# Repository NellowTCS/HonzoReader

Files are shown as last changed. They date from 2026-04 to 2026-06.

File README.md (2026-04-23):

# PocketMage PDA
[Please note that this project is in Beta]

@Ashtf 2025





# [Project Summary]
  This project is a PDA powered by an ESP32-S3 running a custom OS written in C++ using PlatformIO. This project utilizes an E-Ink and OLED screen in tandem to mitigate the refresh rate restrictions of an E-Ink panel while retaining the aesthetics and benefits of using E-Ink. This project is a work in progress and currently amounts to a simple GUI for navigating between apps, a text (.txt) file editor, and a basic file manager. More applications are planned for the future and a list of TO-DOs can be found below.

  At this point, the plan for this project is to get the software and hardware to maturity and once a finished product is achieved, a few things will happen. First, the project files (Code, KiCad schematics, 3D files) will be open-sourced and free for anyone to access. Next, I will likely begin selling kits that allow people to purchase all the parts required to build a device for themselves if they don't want to source the parts themselves. Finally, the community will be encouraged to help develop the software for the device and hopefully push it even further than I could myself.

  I will try my best to keep this GitHub up to date with the development of the device.

# [Getting Started]
**Helpful Resources:**

[FAQ](https://ashtf8.github.io/PocketMage_PDA/docs/faq)

[Tutorials](https://ashtf8.github.io/PocketMage_PDA/docs/tutorials)

[PocketMage Command & Keystroke Manual](https://ashtf8.github.io/PocketMage_PDA/docs/command-manual)

[3rd Party App Template](https://github.com/ashtf8/PocketMage_PDA/blob/main/Code/PocketMage_V3/src/APP_TEMPLATE.cpp)

  Check the [APP_TEMPLATE.cpp](./Code/PocketMage_V3/src/APP_TEMPLATE.cpp) and [/Code/PocketMage_V3/src/readme.md](./Code/PocketMage_V3/src/readme.md) file for more information. Check out the following video as a tutorial on how to create and format your app:
[Developing For the PocketMage](https://www.youtube.com/watch?v=3Ytc-3-BbMM)

# [Hardware]
- ESP32-S3 WROOM1 with 16mb flash and 8mb RAM. WiFi and Bluetooth supported.
- 3.1" 320x240px 1-bit SPI Eink panel (GDEQ031T10) with integrated driver
- 256x32px 1-bit SPI OLED (SSD1326, ER-OLED018-1W) with integrated driver
- MicroSD card slot with support for up to 2TB
- TCA8418 I2C Keyboard Matrix IC
- Piezo Buzzer (Simple Tones)
- Power Button
- 1200mAh pouch-style LiPo battery with JST PH (2mm) connector
- USB Type-C connector
- PCF8563T I2C RTC (Real Time Clock) module
- Expansion port with the following breakouts:
    - +3.3v
    - GND
    - I2C SDA
    - I2C SCL
    - SPI MOSI
    - SPI SCK
    - SPI MISO
    - GPIO A
    - GPIO B
    - GPIO C
    - GPIO D / UART TX (changeable with solder jumper, default TX)
    - GPIO E / UART RX (changeable with solder jumper, default RX)

# [Software]
- Text editor app
- FileWizard file-management app
- Calendar app
- USB file transfer app
- Settings app
- Tasks app
- Journal app
- Dictionary app (Lexicon)
- Basic commands supported through the home menu:
    - roll dN (dice roll, N=number of sides)
    - set time and date
    - directly open files in Notes or FileWiz by typing the name
    - etc.

# [Planned Features]
- Timers and alarms
- E-book reader
- WiFi notes/calendar sync (Google Docs/Calendar)
- LoRa/Meshtastic add-on module
- Battery expansion add-on module
- Custom abbreviations
- Bluetooth keyboard support

# License
All files are distributed under Apache-2.0 license:

PocketMage PDA - A clamshell note-taking and productivity device using E-Ink and OLED.



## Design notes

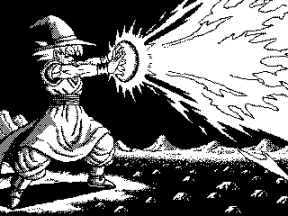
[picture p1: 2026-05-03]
Resources/Assets/screensavers/powerbeam_forest927.bmp

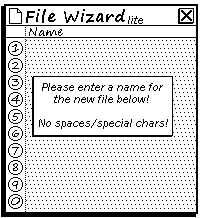
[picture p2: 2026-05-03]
Resources/Assets/File Wizard/fileWizLite3.bmp

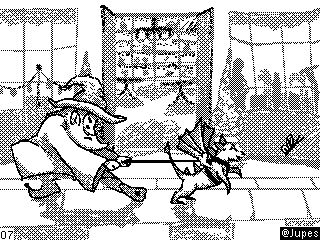
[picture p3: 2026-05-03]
Resources/Assets/ScreenSaver/New folder/classic (8).bmp

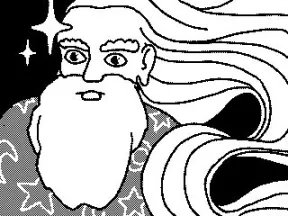
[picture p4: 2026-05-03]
Resources/Assets/screensavers/beautifulhair_b4by_dr1v3r.bmp

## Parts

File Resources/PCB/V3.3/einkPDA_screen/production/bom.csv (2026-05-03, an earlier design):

Designator | Footprint | Quantity | Value | LCSC Part #
C1, C10, C3, C4, C5, C6, C7, C8, C9 | 0402 | 9 | 1uF | C52923
C11 | 0805 | 1 | 4.7uF | C1779
C12, C2 | 0402 | 2 | 4.7uF | C23733
C13, C14 | 0402 | 2 | 0.1uF | C1525
D1, D2, D3 | D_SOD-123 | 3 | MBR0530 | C77336
J2 | AFE03-S25FMA-1H | 1 | ~ | C262544
J3 | TouchSlider-9_50x10mm | 1 | CapacitiveTouch
J4 | AFC01-S12FCA-00 | 1 | Conn_01x12_Pin | C262661
L1 | L_Cenker_CKCS5020 | 1 | 10uH | C52281
Q1 | SOT-323_SC-70 | 1 | Si1308EDL | C7603347
R1 | 0603 | 1 | 0.47R | C3013349
R2 | 0805 | 1 | 10k | C17414
R3 | 0603 | 1 | 75k | C23242
RN1 | R_Array_Concave_4x0603 | 1 | 4x10k | C29718
U1 | UQFN-20_3x3mm_P0.4mm | 1 | MPR121QR2 | C91322

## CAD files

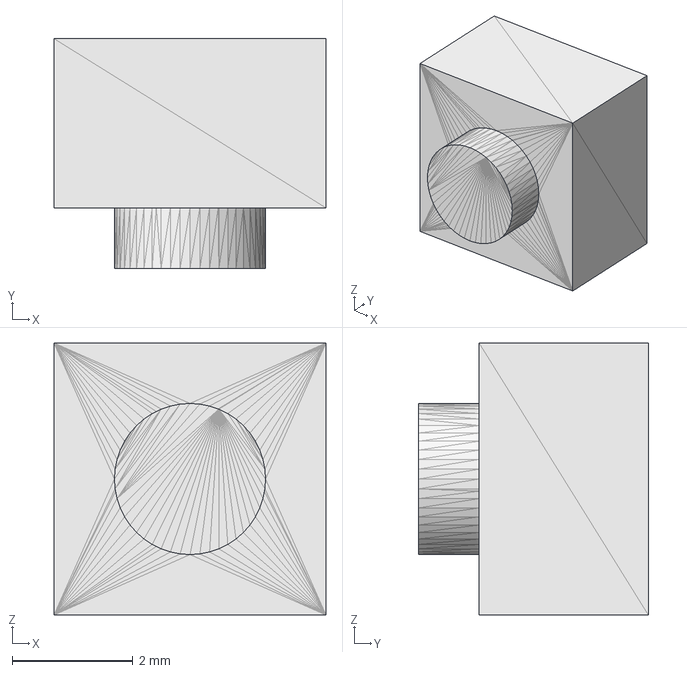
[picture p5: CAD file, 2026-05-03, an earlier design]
Resources/PCB/V3.3/einkPDA_keyboard/JLC_Parts/YTS-C017-2B.step
4.50 x 3.80 x 4.50 mm

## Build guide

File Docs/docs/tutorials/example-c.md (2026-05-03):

---
title: "PocketMage Script Example: Basic Input/Output"
description: "A simple PocketMage script demonstrating user input, OLED output, and terminal printing."
---

# Scripting Example: Basic Input/Output

```c
// PocketMage scripting example
// Based on Wrench by jingoro2112 (GH)
// Edit with potion: pot example.c
// Compile and run: brew example.c

// Declare a variable
var x = ""; // "" indicates str

// Prompt user to enter number
// Set x to entered number
x = prompt("Enter a number");

// Display x on OLED
oledWord(x);

// Print x to terminal
print(x);

// Update the terminal
// (refresh the OLED)
updateTerm();

// Initialize an iteration var i
var i = 0;

// Loop while i < x
// Us toInt to convert str to int
while (i < toInt(x)) {
  // Iterate
  i = i + 1;

  // Display i on OLED
  oledWord(i);

  // Wait 500ms
  delay(500);
}

// Print the final i to the term
print(i);

// Generate a random number
var randomInt = random(0, 100);
print("Random Number: " + randomInt);

// Update the terminal
// (refresh the OLED)
updateTerm();
```

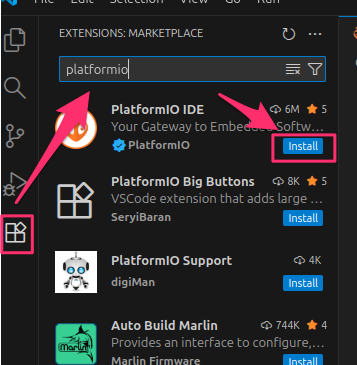
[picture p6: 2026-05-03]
Docs/assets/images/PlatformIO_IDE_install.png

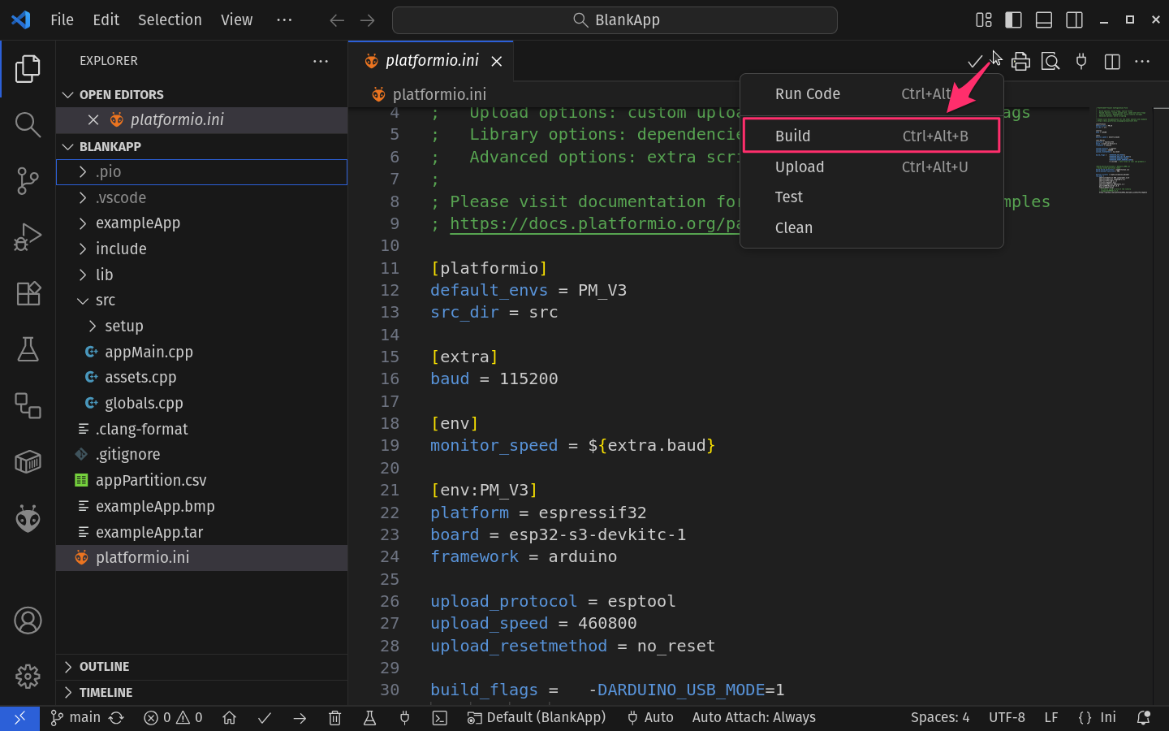
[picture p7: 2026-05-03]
Docs/assets/images/PlatformIO_in_VS_Code_Build.png

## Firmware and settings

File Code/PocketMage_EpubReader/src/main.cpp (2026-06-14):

#include <globals.h>
#include <pocketmage_oled.h>
#include <SD_MMC.h>
#include "reader.h"

#if OTA_APP

static void appTask(void*) {
    for (;;) {
        processKB_APP();
        vTaskDelay(50 / portTICK_PERIOD_MS);
        yield();
    }
}

void setup() {
    PocketMage_INIT();
    xTaskCreatePinnedToCore(appTask, "appTask", 32768, NULL, 2, NULL, 0);
    APP_INIT();
}

void loop() {
    vTaskDelay(pdMS_TO_TICKS(100));
    yield();
}

// E-ink handler task (created by setupEink in PocketMage library)
void einkHandler(void*) {
    vTaskDelay(pdMS_TO_TICKS(250));
    for (;;) {
        einkHandler_APP();
        vTaskDelay(pdMS_TO_TICKS(50));
        yield();
    }
}

// APP_INIT
void APP_INIT() {
    library_init();
    updateOLED();
}

// processKB_APP
void processKB_APP() {
    char ch = KB().updateKeypress();

    // Touch bar handling (runs every cycle in reading mode)
    if (g_appMode == MODE_READING) {
        touch_scroll();
    }

    if (!ch) return;

    // System-level commands (always handled)
    if (ch == 18) {  // FN key toggle
        KB().setKeyboardState(KB().getKeyboardState() == FUNC ? NORMAL : FUNC);
        return;
    }
    if (ch == 12) {  // FN+< is save & exit to OS
        KB().setKeyboardState(NORMAL);
        if (g_appMode == MODE_READING || g_appMode == MODE_TOC || g_appMode == MODE_JUMP) {
            saveBookmark();
        }
        rebootToPocketMage();
        return;
    }
    if (ch == 27 || ch == 65) {  // ESC or A is exit to OS
        if (g_appMode == MODE_READING || g_appMode == MODE_TOC || g_appMode == MODE_JUMP) {
            saveBookmark();
        }
        rebootToPocketMage();
        return;
    }
    if (ch == 17) {  // SHIFT
        KB().setKeyboardState(KB().getKeyboardState() == SHIFT ? NORMAL : SHIFT);
        return;
    }

    // Dispatch to current mode
    switch (g_appMode) {
        case MODE_LIBRARY: library_process_key(ch); break;
        case MODE_READING: reader_process_key(ch);  break;
        case MODE_TOC:     toc_process_key(ch);      break;
        case MODE_JUMP:    jump_process_key(ch);     break;
        case MODE_HELP:    g_appMode = MODE_READING; g_needsRedraw = true; break;
    }

    updateOLED();
}

// einkHandler_APP
void einkHandler_APP() {
    if (!g_needsRedraw) { updateOLED(); return; }
    g_needsRedraw = false;
    switch (g_appMode) {
        case MODE_HELP:    help_render();    break;
        case MODE_LIBRARY: library_render(); break;
        case MODE_TOC:     toc_render();     break;
        case MODE_JUMP:    jump_render();    break;
        case MODE_READING: reader_render();  break;
    }
    updateOLED();
}

#endif // OTA_APP

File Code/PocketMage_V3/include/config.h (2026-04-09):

#ifndef CONFIG_H
#define CONFIG_H

// OTA App
// Is this an OTA APP? // OTA_APP: set -DOTA_APP_FLAG=1 in platformio.ini
#if OTA_APP_FLAG
#define OTA_APP true
#else
#define OTA_APP false
#endif

// CONFIGURATION & SETTINGS
////////////////////////////////////////////////////////////////////////////////////////////////////////////////////////////|
#define KB_COOLDOWN 3                           // Keypress cooldown
#define FULL_REFRESH_AFTER 5                    // Full refresh after N partial refreshes (CHANGE WITH CAUTION)
#define MAX_FILES 10                            // Number of files to store
#define FORMAT_SPIFFS_IF_FAILED true            // Format the SPIFFS filesystem if mount fails
#define SLEEPMODE "TEXT"                        // TEXT, SPLASH, CLOCK
#define TXT_APP_STYLE 1                         // 0: Old Style (NOT SUPPORTED), 1: New Style
#define SET_CLOCK_ON_UPLOAD false               // Should system clock be set automatically on code upload?
#define TOUCH_TIMEOUT_MS 1200                   // Delay after scrolling to return to typing mode (ms)
#define SYS_METADATA_FILE "/sys/SDMMC_META.txt" // File path to the file system metadata file
#define POWER_SAVE_FREQ 40                      // CPU freq for power save mode
#define IDLE_TIME 20000                         // time to wait for mage idle (ms)
////////////////////////////////////////////////////////////////////////////////////////////////////////////////////////////|

// PIN DEFINITION
#define I2C_SCL       35
#define I2C_SDA       36
#define MPR121_ADDR   0x5A
#define MP2722_ADDR   0x3F
#define USB_MUX_PIN   7

#define KB_IRQ        8
#define PWR_BTN       0 
#define BAT_SENS      4
#define CHRG_SENS     39
#define RTC_INT       1 

// SPI
#define SPI_MOSI      14
#define SPI_SCK       15

// OLED
#define OLED_CS       47
#define OLED_DC       46
#define OLED_RST      45

// E Ink
#define EPD_CS        2
#define EPD_DC        21
#define EPD_RST       9
#define EPD_BUSY      37

// SDMMC mode
#define SD_CLK        12
#define SD_CMD        11
#define SD_D0         13
#define SD_D1         5
#define SD_D2         6

// SDSPI mode
#define SD_CS         10
#define SD_MOSI       11
#define SD_SCK        12
#define SD_MISO       13

#define BZ_PIN        17

// ===================== SYSTEM SETTINGS =====================
// Persistent preferences
extern int TIMEOUT;              // Auto sleep timeout (seconds)
extern bool DEBUG_VERBOSE;       // Extra debug output
extern bool SYSTEM_CLOCK;        // Show clock on screen
extern bool SHOW_YEAR;           // Show year in clock
extern bool SAVE_POWER;          // Enable power saving mode
extern bool ALLOW_NO_MICROSD;    // Allow running without SD card
extern bool HOME_ON_BOOT;        // Start home app on boot
extern int OLED_BRIGHTNESS;      // OLED brightness (0-255)
extern int OLED_MAX_FPS;         // OLED max FPS
extern bool SD_SPI_COMPATIBILITY;

#endif

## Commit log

2026-02-16 WIP PCB updates
    [einkPDA_keyboard.kicad_pcb]
2026-03-05 Change ESP32 from N16R8 to N16
2026-03-12 Update PCB
    [bom.csv, designators.csv, einkPDA_screen.kicad_pcb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]
2026-04-13 PCB updates
    [einkPDA_keyboard.kicad_sch]
2026-05-03 Improve slow full update system for prod boards
2026-06-16 I'm a bit tired apparently /j [ci skip]
2026-06-21 Various bug fixes and improvements
    [app_renderer.cpp]
